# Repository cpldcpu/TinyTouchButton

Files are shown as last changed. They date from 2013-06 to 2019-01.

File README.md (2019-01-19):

TinyTouchButton
===============

A touch controlled light with 4xWS2812 RGB LEDs and ATtiny 10

This is a small hardware project which utilizes the [light_WS2812 library](https://github.com/cpldcpu/light_ws2812) and the [TinyTouchLib](https://github.com/cpldcpu/TinyTouchLib) 
to implement a touch-button controlled RGB-LED light. Only two output pins of the ATtiny 10 
are used.

Atmel Studio project and Eagle files are included.

New: Hardware V2.0. See [subfolder](https://github.com/cpldcpu/TinyTouchButton/tree/master/Eagle%20Hardware%20V2.0).

### Finished PCB V1.0 ###

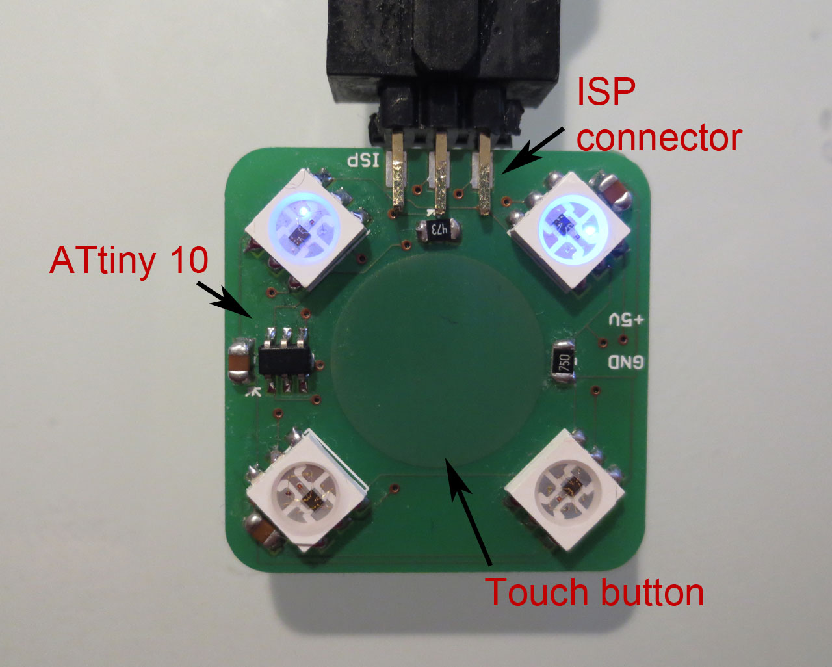
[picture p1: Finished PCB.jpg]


### Finished PCB V2.0 ###

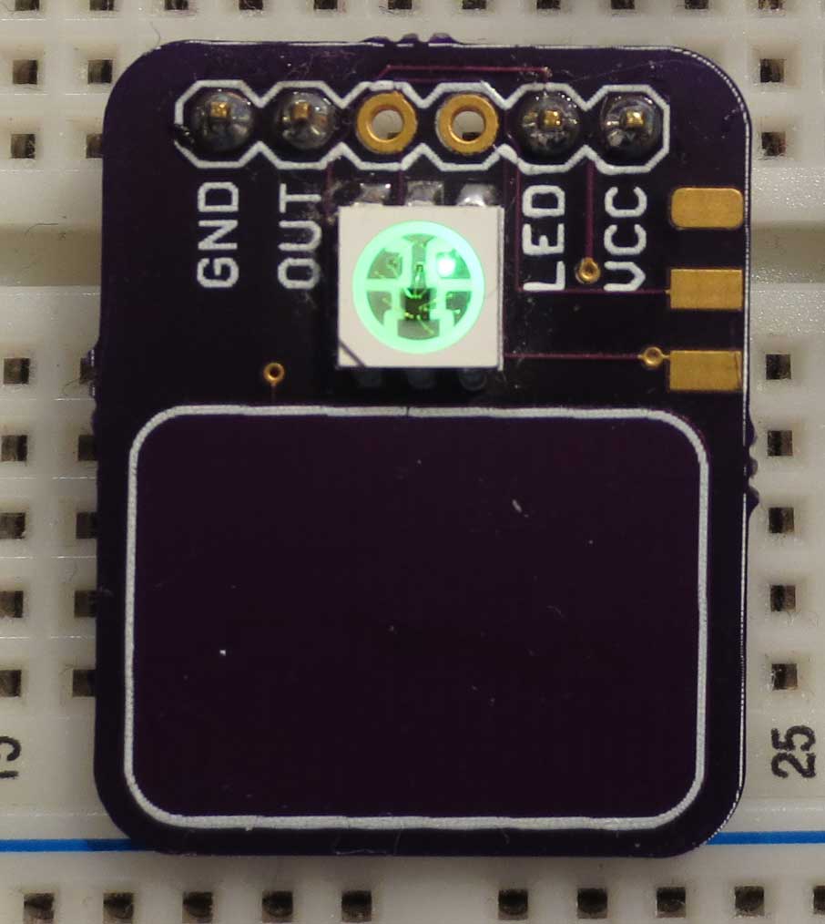
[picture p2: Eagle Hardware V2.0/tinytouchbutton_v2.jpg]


### Circuit ###

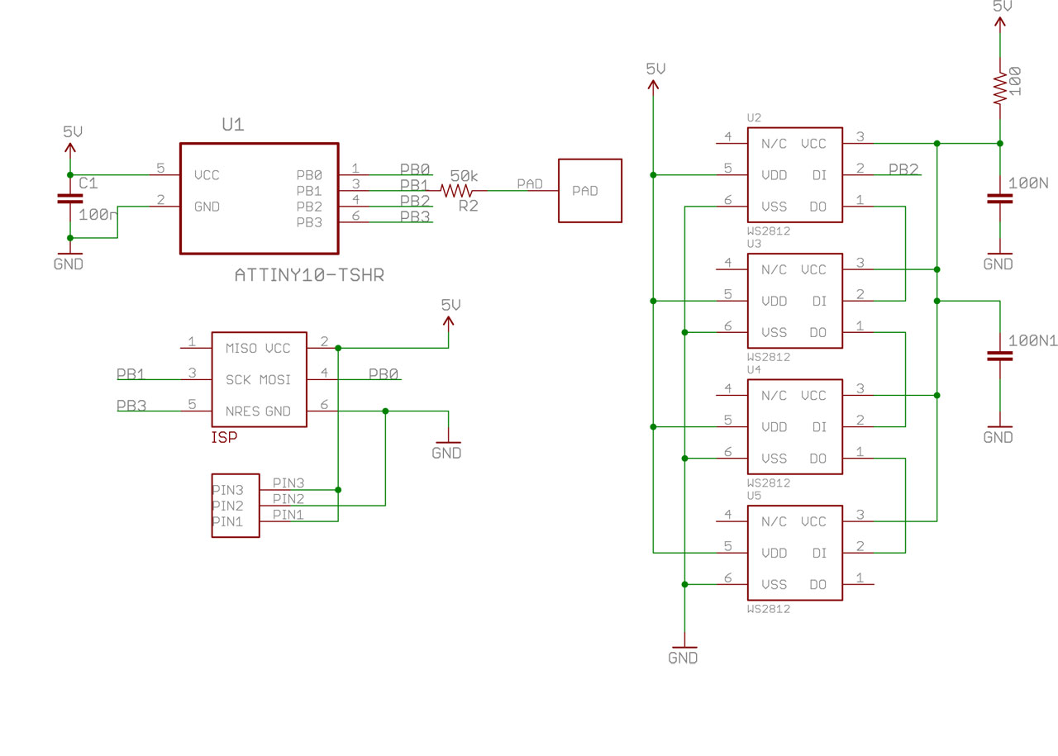
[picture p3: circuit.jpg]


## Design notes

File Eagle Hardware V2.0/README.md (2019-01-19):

TinyTouchButton Hardware V2.0
===============

A touch controlled light with a WS2812 RGB LEDs and ATtiny 10

This is a small hardware project which utilizes the [light_WS2812 library](https://github.com/cpldcpu/light_ws2812) and the [TinyTouchLib](https://github.com/cpldcpu/TinyTouchLib) 
to implement a touch-button controlled RGB-LED light. Only two output pins of the ATtiny 10 
are used.

Look at the button in operation [here](http://www.youtube.com/watch?v=yGvvy51Po7Q)!

### PCB renders by OSH Park ###

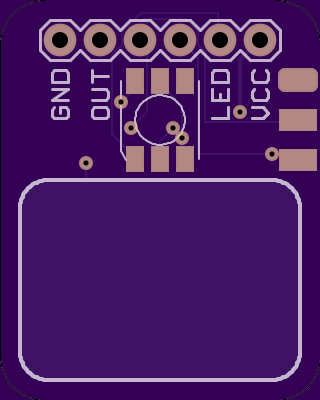
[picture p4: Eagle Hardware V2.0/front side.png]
  
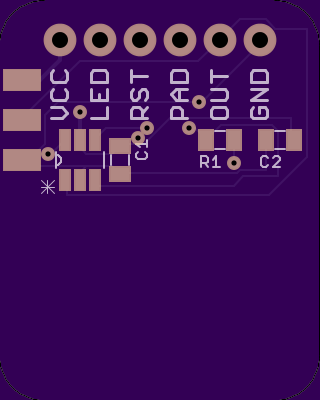
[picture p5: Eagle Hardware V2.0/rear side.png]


### Finished PCB ###

PCB

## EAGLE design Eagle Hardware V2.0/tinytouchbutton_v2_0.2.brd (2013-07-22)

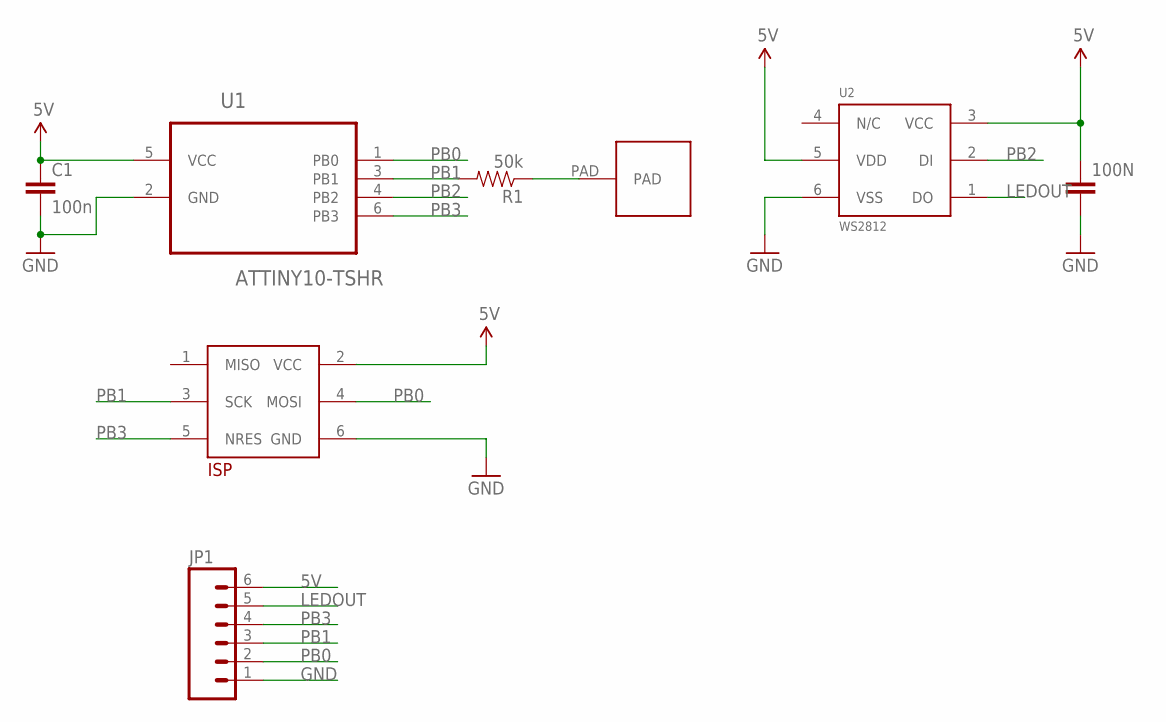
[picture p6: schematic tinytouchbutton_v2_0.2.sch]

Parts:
100N: CAP0805; 0805
C1: 100n; 0805
JP1: M06SIP; 1X06
R1: 50k; 0805
U1: ATTINY10-TSHR; SOT95P280X145-6N
U2: WS2812; PLCC6
U$1: TB_ISPEDGE_2X3; ISP_EDGE2X3
U$2: TB_TOUCH_0.5INCH; TOUCH_ROUND0.5INCH

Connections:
5V: 100N.1, C1.1, JP1.6, U1.5 (VCC), U2.3 (VCC), U2.5 (VDD), U$1.2 (VCC)
GND: 100N.2, C1.2, JP1.1, U1.2 (GND), U2.6 (VSS), U$1.6 (GND)
LEDOUT: JP1.5, U2.1 (DO)
PAD: R1.1, U$2.PAD
PB0: JP1.2, U1.1 (PB0), U$1.4 (MOSI)
PB1: JP1.3, R1.2, U1.3 (PB1), U$1.3 (SCK)
PB2: U1.4 (PB2), U2.2 (DI)
PB3: JP1.4, U1.6 (PB3), U$1.5 (NRES)

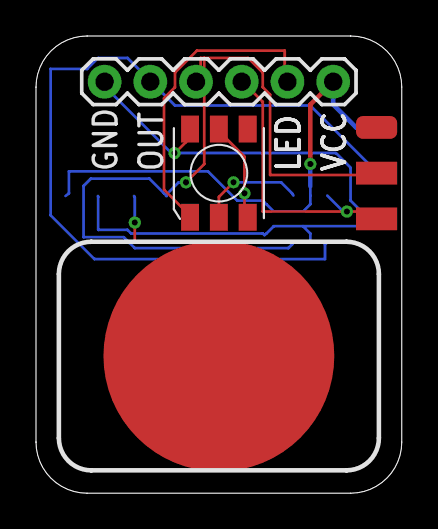
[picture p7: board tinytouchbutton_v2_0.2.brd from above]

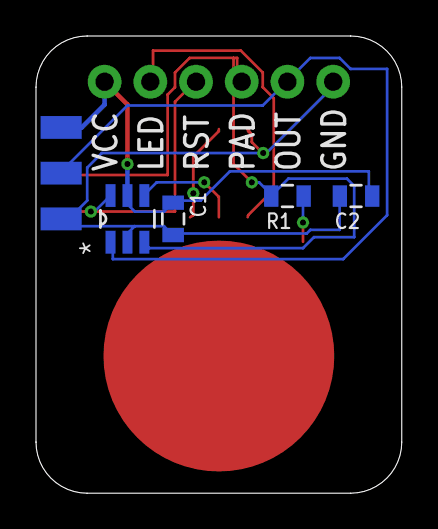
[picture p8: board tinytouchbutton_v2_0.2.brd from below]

Board: 2 copper layers, 20.3 x 25.4 mm, 8 parts (4 on the bottom side), 8 nets.

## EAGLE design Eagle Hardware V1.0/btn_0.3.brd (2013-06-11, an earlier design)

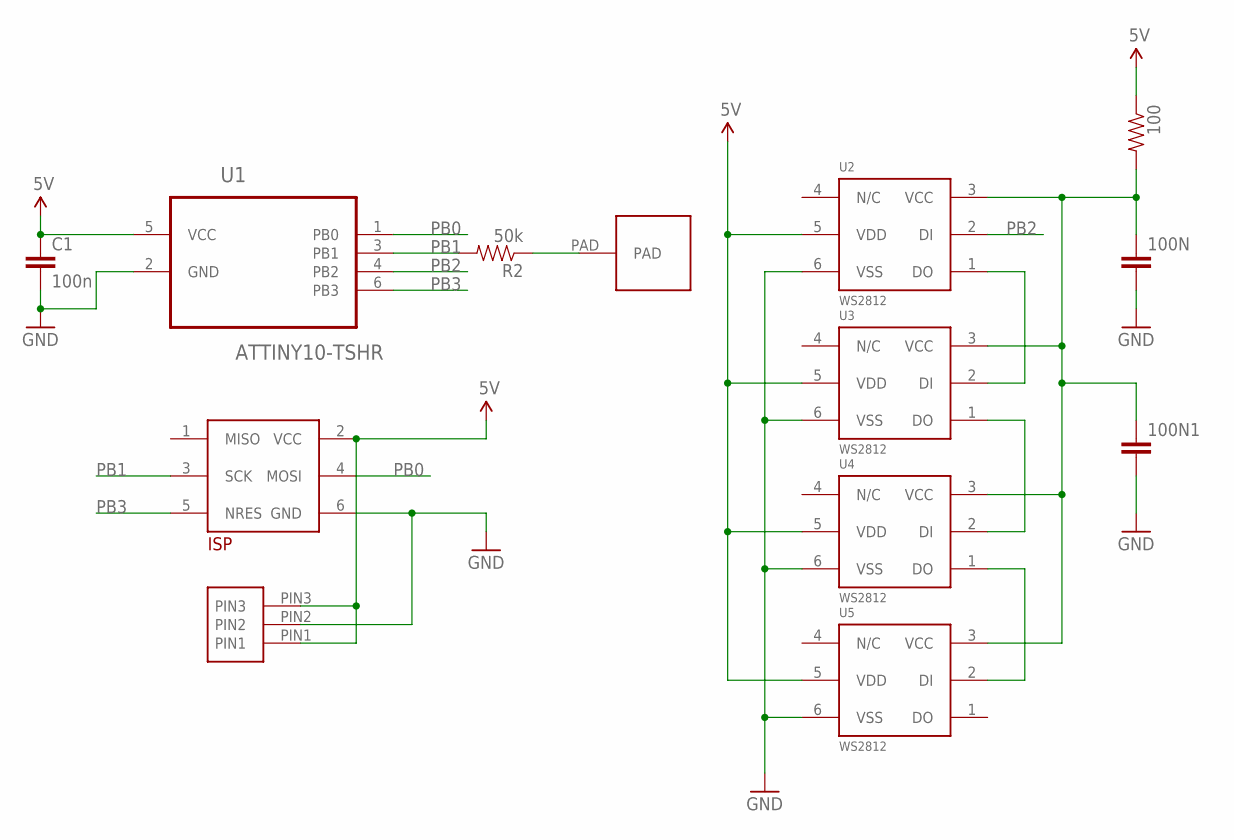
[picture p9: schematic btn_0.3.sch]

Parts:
100: RESISTOR0805-RES; 0805
100N, 100N1: CAP0805; 0805
C1: 100n; 0805
R2: 50k; 0805
U1: ATTINY10-TSHR; SOT95P280X145-6N
U2, U3, U4, U5: WS2812; PLCC6
U$1: TB_ISPEDGE_2X3; ISP_EDGE2X3
U$2: TB_TOUCH_0.5INCH; TOUCH_ROUND0.5INCH
U$4: TB_EDGE3

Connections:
5V: 100.1, C1.1, U1.5 (VCC), U2.5 (VDD), U3.5 (VDD), U4.5 (VDD), U5.5 (VDD), U$1.2 (VCC), U$4.PIN1, U$4.PIN3
GND: 100N.2, 100N1.2, C1.2, U1.2 (GND), U2.6 (VSS), U3.6 (VSS), U4.6 (VSS), U5.6 (VSS), U$1.6 (GND), U$4.PIN2
unnamed: R2.1, U$2.PAD
unnamed: U2.1 (DO), U3.2 (DI)
unnamed: U3.1 (DO), U4.2 (DI)
unnamed: U4.1 (DO), U5.2 (DI)
unnamed: 100.2, 100N.1, 100N1.1, U2.3 (VCC), U3.3 (VCC), U4.3 (VCC), U5.3 (VCC)
PB0: U1.1 (PB0), U$1.4 (MOSI)
PB1: R2.2, U1.3 (PB1), U$1.3 (SCK)
PB2: U1.4 (PB2), U2.2 (DI)
PB3: U1.6 (PB3), U$1.5 (NRES)

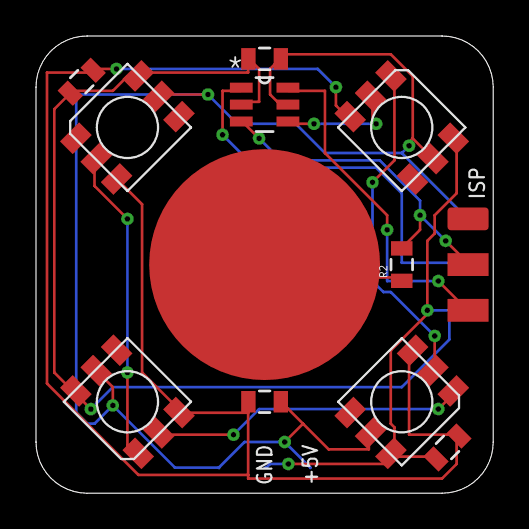
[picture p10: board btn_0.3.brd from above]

Board: 2 copper layers, 25.4 x 25.4 mm, 13 parts (1 on the bottom side), 11 nets.

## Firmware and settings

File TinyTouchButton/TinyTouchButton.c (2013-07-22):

/*
 * TinyTouchButton.c
 *
 * Created: 31.05.2013 18:13:26
 *  Author: Tim

 Hardware:
	- Attiny 10
	- 4x WS2812 LED on PB2
	- Touchbutton on PB1
 */ 

#define F_CPU 8000000

#include <avr/io.h>
#include <util/delay.h>
#include "light_ws2812.h"
#include "TinyTouchLib.h"
	
struct CRGB { uint8_t g; uint8_t r; uint8_t b; };
struct CRGB led[4];

int main(void)
{
	uint8_t ledon=0;
	uint8_t ctr;
	
	CCP=0xD8;		// configuration change protection, write signature
	CLKPSR=0;		// set cpu clock prescaler =1 (8Mhz) (attiny 4/5/9/10)

	DDRB|=_BV(PB2);  // Output pin for WS2812
	DDRB|=_BV(PB0);  // Data output

	tinytouch_init();
	
    while(1)
    {
		if (tinytouch_sense()==tt_push) {ledon^=1;}
			
		ctr++;
			
		if (ledon) {
			led[0].r=128;led[0].g=128;led[0].b=128;  // light on: white on maximum brightness
			led[1].r=255;led[1].g=255;led[1].b=255;
			led[2].r=255;led[2].g=255;led[2].b=255;
			led[3].r=255;led[3].g=255;led[3].b=255;
			PORTB|=_BV(PB0);
		} else {
			led[0].r=0;led[0].g=0;led[0].b=0;		// 	light off: Attract mode.
			led[1].r=0;led[1].g=0;led[1].b=0;
			led[2].r=0;led[2].g=0;led[2].b=0;
			led[3].r=0;led[3].g=0;led[3].b=0;
			led[ctr>>6].g=((ctr&0x3f)^0x3f)>>3;  
			led[((ctr>>6)+1)&3].g=(ctr&0x3f)>>3;
			PORTB&=~_BV(PB0);
		}		
		
		ws2812_sendarray_mask(led,12,_BV(PB2));
		_delay_ms(3);
    }
}

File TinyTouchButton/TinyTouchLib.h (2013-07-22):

/*
 * TinyTouchLib.h
 *
 * Created: 09.06.2013 17:25:47			-	v0.1 Initial release
 *  Author: Tim (cpldcpu@gmail.com) 
 */ 


#ifndef TINYTOUCHLIB_H_
#define TINYTOUCHLIB_H_
#include <avr/io.h>

enum {tt_off=0,tt_on,tt_push,tt_release,tt_timeout};

//////////////////////////////////////////////////////////////////////////
//
// User definable settings
//
//////////////////////////////////////////////////////////////////////////

// Define upper and lower threshold for the touch sensing. You may have to
// change these depending on the geometry of your touch button.
// Setting the "on" value lower will make the touch button more sensitive.
// Setting the "off" value higher will make the touch button less likely
// to be "stuck". Too high values can lead to oscillations.

#define touch_threshold_on 70
#define touch_threshold_off 20

// If the touch button is pressed, the bias value is not updated
// to prevent detection of multiple touches. In some cases this may
// lead to a "stuck button" situation. Therefore an update of the bias
// is forced after a certain time unless this function is deactivated.
//
// The value of timeout corresponds to the number of calls to tinytouch_sense().
// The maximum is 255. 
// Setting timeout to 0 will turn the functionality off.

#define touch_timeout 255
//#define touch_timeout 0		// turn off timeout functionality


// Define pins to use for the reference input and the touch button
// The reference pin is used to charge or discharge the internal
// sample&hold capacitor. This pin is used in output mode and should
// not be shorted to VCC or GND externally.
// The sense pin is connected to the touch-button. To improve noise immunity
// a series resistor can be used.

// The pin number corresponds to the analog input number ADCx. The port
// is chosen automatically. (PORTB on ATtiny 5/10/13/25/45/85)

#define tt_refpin 2		// Use PB0 as reference pin
#define tt_refadc 2		// Use ADC0 as reference ADC input
#define tt_sensepin 1	// Use PB1 as sense pin
#define tt_senseadc 1	// Use ADC1 as sense ADC input
			
//////////////////////////////////////////////////////////////////////////
//
// Library functions
//
//////////////////////////////////////////////////////////////////////////

// Library initialization
// Call this once to initialize the library functions and the ADC converter
void	tinytouch_init(void);

// The sense function evaluates the button state and performs internal 
// housekeeping. It should be polled at least 30 times per second to
// update the internal logic. Please note that each call performs 32
// analog to digital conversions with active waiting. This may take 
// several ms.

// Possible return values are:
//		tt_off=0	No touch sensed
//		tt_on		Touch button is active and touch is sensed.
//		tt_push		Touch button is pushed. Use this to initiate one time events.
//		tt_release	Touch button is released. Use this to initiate one time events.
//		tt_timeout	Touch button has been active too long and internal bias was	reset. 
uint8_t tinytouch_sense(void);

#endif

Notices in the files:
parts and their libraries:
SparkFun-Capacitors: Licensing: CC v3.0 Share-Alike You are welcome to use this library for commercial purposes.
